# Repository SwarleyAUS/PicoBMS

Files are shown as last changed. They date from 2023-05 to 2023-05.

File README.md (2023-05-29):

# PicoBMS
Raspberry Pi Pico-based Battery Management System for 6-24S Lithium battery packs

Devleoped in KiCAD

Functionality:
- 6-24S cell monitoring and balancing through LTC6803-3
- XT30 charge and battery ports
- JST-XH balance jacks (12P & 13P)
- Dual thermister inputs
- Charge current sensing
- Opto-isolated CAN breakout from Pi Pico
- Back to back input MOSFETs for discharge protection

*** THIS DESIGN IS THEORETICALLY COMPLETE BUT UNTESTED ***



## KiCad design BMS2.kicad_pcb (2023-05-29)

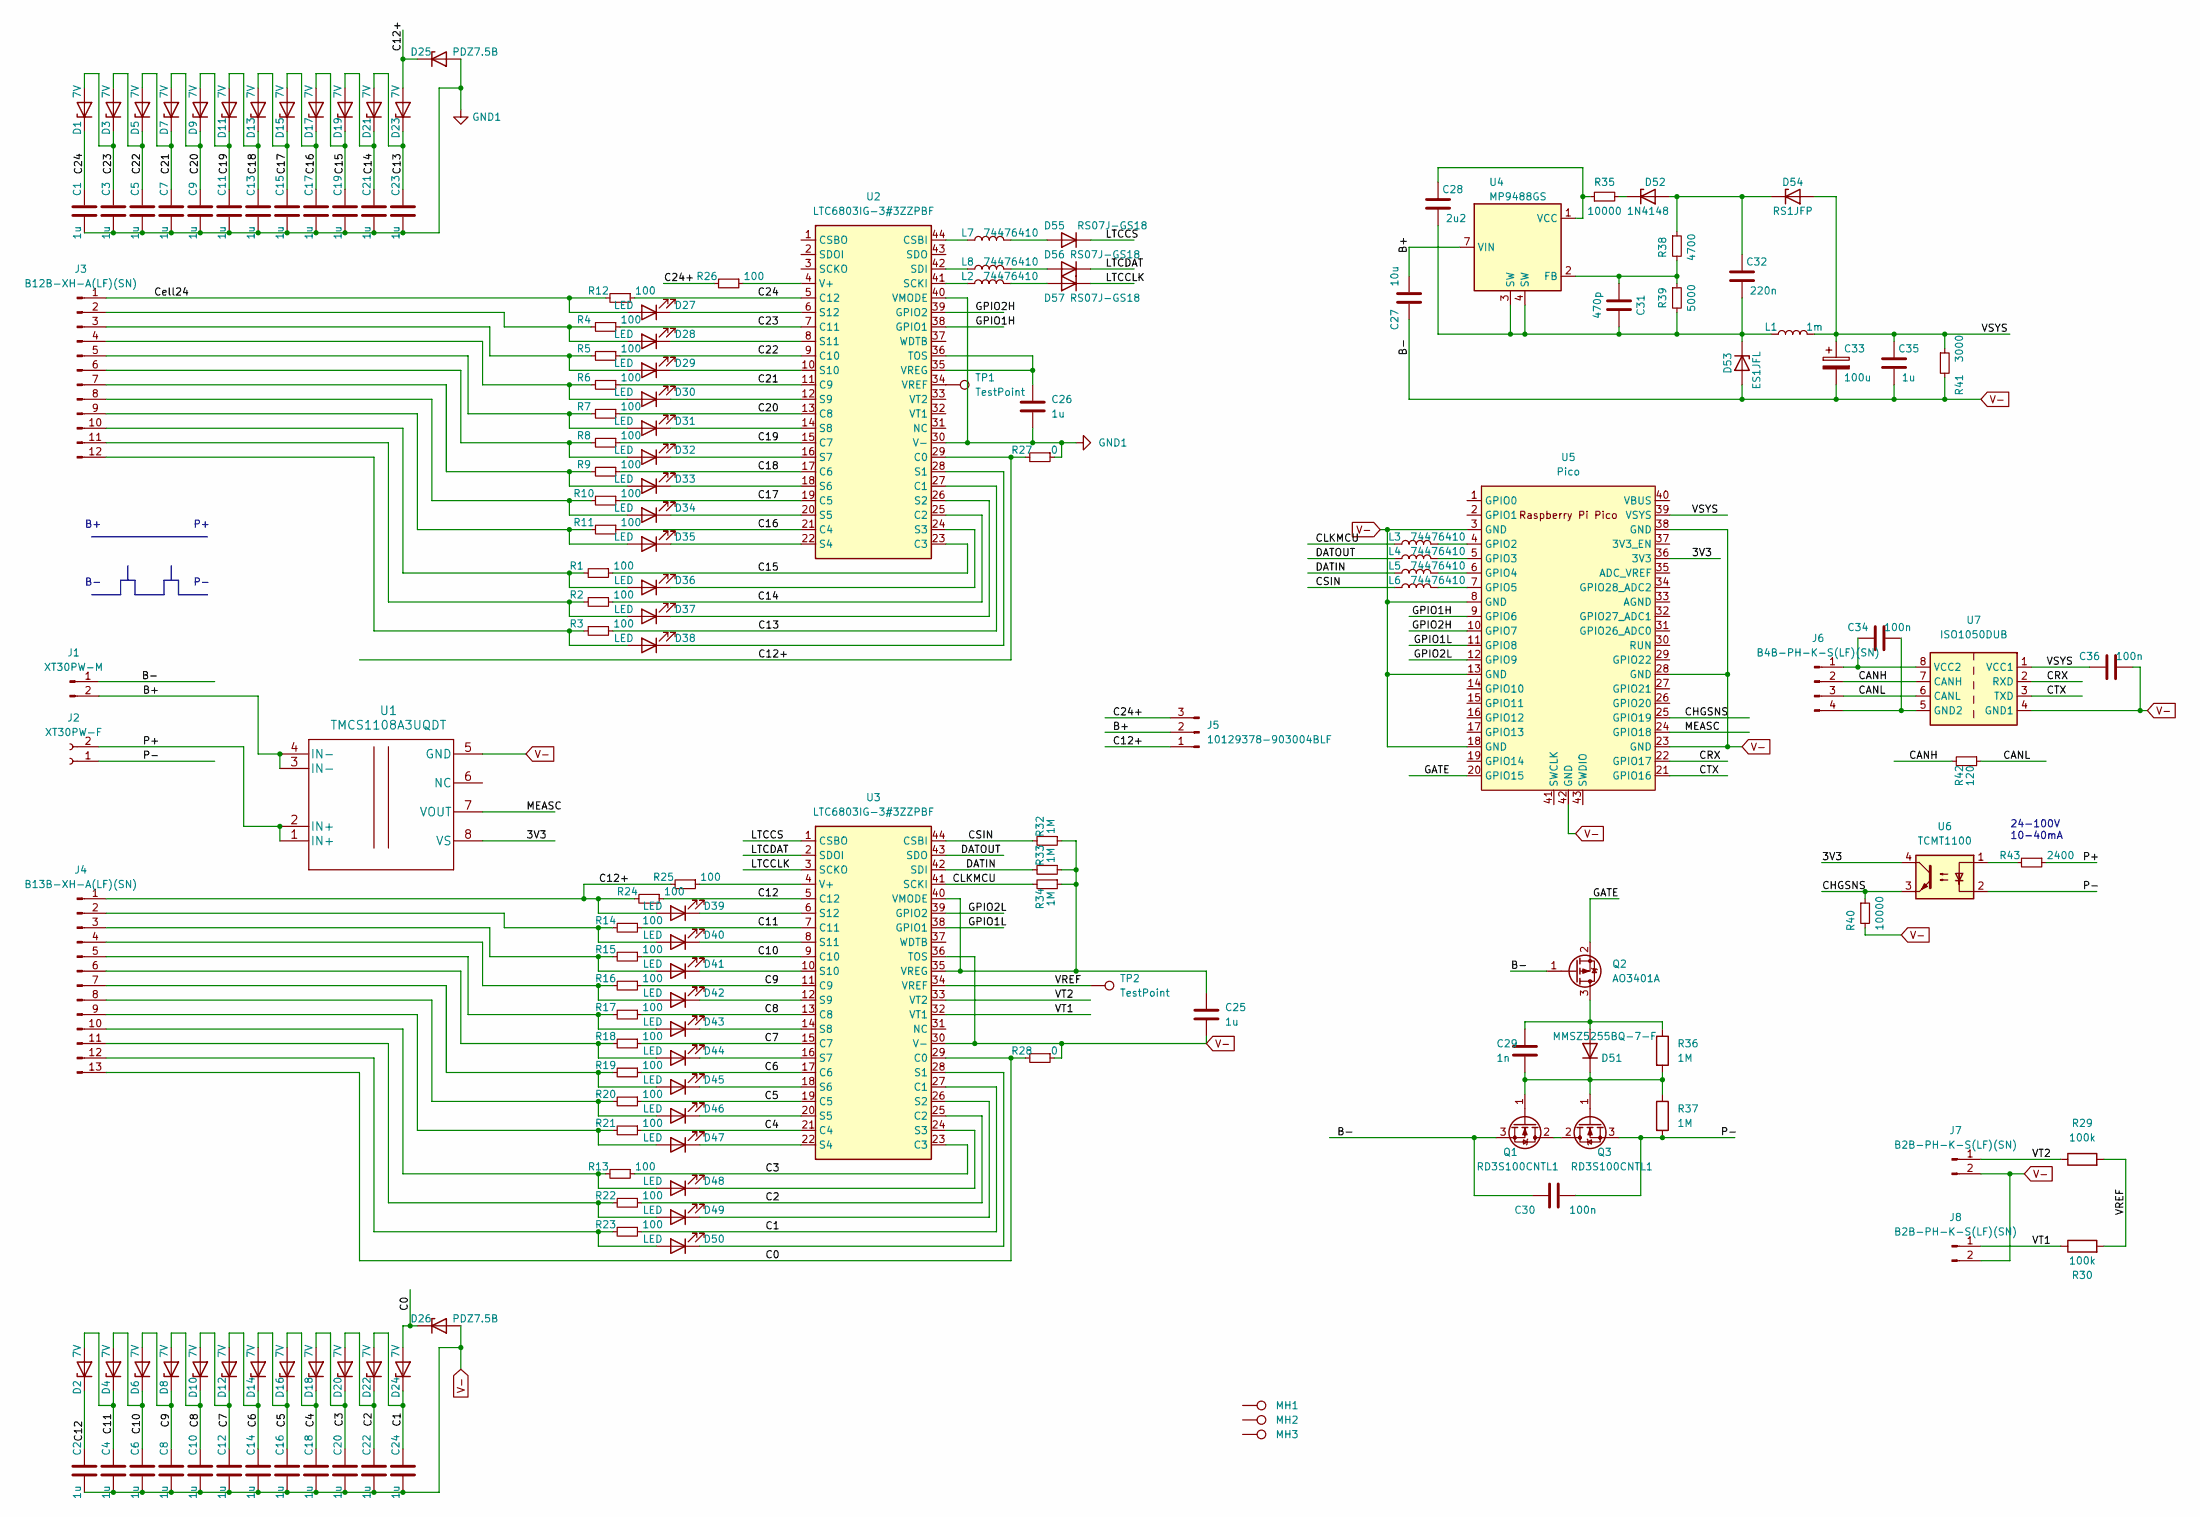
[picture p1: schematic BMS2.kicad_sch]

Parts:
C1, C2, C3, C4, C5, C6, C7, C8, C9, C10, C11, C12, C13, C14, C15, C16, C17, C18, C19, C20, C21, C22, C23, C24, C25, C26, C35: 1u; C_0603_1608Metric
C27: 10u; C_1210_3225Metric
C28: 2u2; C_0603_1608Metric
C29: 1n; C_0603_1608Metric
C30, C34, C36: 100n; C_0603_1608Metric
C31: 470p; C_0603_1608Metric
C32: 220n; C_0603_1608Metric
C33: 100u; CP_Elec_5x5.4
D1, D2, D3, D4, D5, D6, D7, D8, D9, D10, D11, D12, D13, D14, D15, D16, D17, D18, D19, D20, D21, D22, D23, D24: 7V; D_SOD-323
D25, D26: PDZ7.5B; D_SOD-323
D27, D28, D29, D30, D31, D32, D33, D34, D35, D36, D37, D38, D39, D40, D41, D42, D43, D44, D45, D46, D47, D48, D49, D50: LED; LED_0603_1608Metric
D51: MMSZ5255BQ-7-F; D_SOD-123
D52: 1N4148; D_SOD-323
D53: ES1JFL; D_SOD-123
D54: RS1JFP; D_SOD-123
D55, D56, D57: RS07J-GS18; D_SMF
J1: XT30PW-M; AMASS_XT30PW-M_1x02_P2.50mm_Horizontal
J2: XT30PW-F; AMASS_XT30PW-F_1x02_P2.50mm_Horizontal
J3: B12B-XH-A(LF)(SN); JST_XH_B12B-XH-A_1x12_P2.50mm_Vertical
J4: B13B-XH-A(LF)(SN); JST_XH_B13B-XH-A_1x13_P2.50mm_Vertical
J5: 10129378-903004BLF; PinHeader_1x03_P2.54mm_Vertical
J6: B4B-PH-K-S(LF)(SN); JST_PH_B4B-PH-K_1x04_P2.00mm_Vertical
J7, J8: B2B-PH-K-S(LF)(SN); JST_PH_B2B-PH-K_1x02_P2.00mm_Vertical
L1: 1m; L_1812_4532Metric
L2, L3, L4, L5, L6, L7, L8: 74476410; L_0805_2012Metric
MH1, MH2, MH3: TestPoint; MountingHole_3.2mm_M3
Q1, Q3: RD3S100CNTL1; TO-252-2
Q2: AO3401A; SOT-23
R1, R2, R3, R4, R5, R6, R7, R8, R9, R10, R11, R12, R13, R14, R15, R16, R17, R18, R19, R20, R21, R22, R23, R24, R25, R26: 100; R_0603_1608Metric
R27, R28: 0; R_0603_1608Metric
R29, R30: 100k; R_0603_1608Metric
R32, R33, R34, R36, R37: 1M; R_0603_1608Metric
R35, R40: 10000; R_0603_1608Metric
R38: 4700; R_0603_1608Metric
R39: 5000; R_0603_1608Metric
R41: 3000; R_0603_1608Metric
R42: 120; R_0603_1608Metric
R43: 2400; R_0603_1608Metric
TP1, TP2: TestPoint; TestPoint_THTPad_D1.5mm_Drill0.7mm
U1: TMCS1108A3UQDT; SOIC-8_3.9x4.9mm_P1.27mm
U2, U3: LTC6803IG-3#3ZZPBF; SSOP-44_5.3x12.8mm_P0.5mm
U4: MP9488GS; SOIC-8_3.9x4.9mm_P1.27mm
U5: Pico; RPi_Pico_SMD_TH
U6: TCMT1100; SOP-4_4.4x2.6mm_P1.27mm
U7: ISO1050DUB; SOP-8_6.62x9.15mm_P2.54mm

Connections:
/3V3: U1.8 (VS), U5.36 (3V3), U6.4
/B+: C27.2, J1.2, J5.2, U1.3 (IN-), U1.4 (IN-), U4.7 (VIN)
/C0: D24.2 (A), D26.1 (K), J4.13, R28.2, U3.29 (C0)
/C1: C24.1, D22.2 (A), D24.1 (K), R23.1, U3.27 (C1)
/C2: C22.1, D20.2 (A), D22.1 (K), R22.1, U3.25 (C2)
/C3: C20.1, D18.2 (A), D20.1 (K), R13.1, U3.23 (C3)
/C4: C18.1, D16.2 (A), D18.1 (K), R21.1, U3.21 (C4)
/C5: C16.1, D14.2 (A), D16.1 (K), R20.1, U3.19 (C5)
/C6: C14.1, D12.2 (A), D14.1 (K), R19.1, U3.17 (C6)
/C7: C12.1, D10.2 (A), D12.1 (K), R18.1, U3.15 (C7)
/C8: C10.1, D8.2 (A), D10.1 (K), R17.1, U3.13 (C8)
/C9: C8.1, D6.2 (A), D8.1 (K), R16.1, U3.11 (C9)
/C10: C6.1, D4.2 (A), D6.1 (K), R15.1, U3.9 (C10)
/C11: C4.1, D2.2 (A), D4.1 (K), R14.1, U3.7 (C11)
/C12: C2.1, D2.1 (K), R24.1, U3.5 (C12)
/C12+: D23.2 (A), D25.1 (K), D39.2 (A), J4.1, J5.1, R24.2, R25.2, R27.2, U2.29 (C0)
/C13: C23.1, D21.2 (A), D23.1 (K), R3.1, U2.27 (C1)
/C14: C21.1, D19.2 (A), D21.1 (K), R2.1, U2.25 (C2)
/C15: C19.1, D17.2 (A), D19.1 (K), R1.1, U2.23 (C3)
/C16: C17.1, D15.2 (A), D17.1 (K), R11.1, U2.21 (C4)
/C17: C15.1, D13.2 (A), D15.1 (K), R10.1, U2.19 (C5)
/C18: C13.1, D11.2 (A), D13.1 (K), R9.1, U2.17 (C6)
/C19: C11.1, D9.2 (A), D11.1 (K), R8.1, U2.15 (C7)
/C20: C9.1, D7.2 (A), D9.1 (K), R7.1, U2.13 (C8)
/C21: C7.1, D5.2 (A), D7.1 (K), R6.1, U2.11 (C9)
/C22: C5.1, D3.2 (A), D5.1 (K), R5.1, U2.9 (C10)
/C23: C3.1, D1.2 (A), D3.1 (K), R4.1, U2.7 (C11)
/C24: C1.1, D1.1 (K), R12.1, U2.5 (C12)
/C24+: J5.3, R26.2
/CANH: J6.2, R42.2, U7.7 (CANH)
/CANL: J6.3, R42.1, U7.6 (CANL)
/CHGSNS: R40.1, U5.25 (GPIO19), U6.3
/CLKMCU: L3.1, R34.2, U3.41 (SCKI)
/CRX: U5.22 (GPIO17), U7.2 (RXD)
/CSIN: L6.1, R32.2, U3.44 (CSBI)
/CTX: U5.21 (GPIO16), U7.3 (TXD)
/Cell24: D27.2 (A), J3.1, R12.2
/DATIN: L5.1, R33.2, U3.42 (SDI)
/DATOUT: L4.1, U3.43 (SDO)
/GATE: Q2.2 (S), U5.20 (GPIO15)
/GPIO1H: U2.38 (GPIO1), U5.9 (GPIO6)
/GPIO1L: U3.38 (GPIO1), U5.11 (GPIO8)
/GPIO2H: U2.39 (GPIO2), U5.10 (GPIO7)
/GPIO2L: U3.39 (GPIO2), U5.12 (GPIO9)
/LTCCLK: D57.1 (K), U3.3 (SCKO)
/LTCCS: D55.1 (K), U3.1 (CSBO)
/LTCDAT: D56.1 (K), U3.2 (SDOI)
/MEASC: U1.7 (VOUT), U5.24 (GPIO18)
/P+: J2.2, R43.1, U1.1 (IN+), U1.2 (IN+)
/P-: C30.2, J2.1, Q3.3 (S), R37.2, U6.2
/VREF: R29.2, R30.2, TP2.1, U3.34 (VREF)
/VSYS: C33.1, C35.1, C36.1, D54.2 (A), L1.2, R41.1, U5.39 (VSYS), U7.1 (VCC1)
/VT1: J8.1, R30.1, U3.32 (VT1)
/VT2: J7.1, R29.1, U3.33 (VT2)
GND1: C1.2, C3.2, C5.2, C7.2, C9.2, C11.2, C13.2, C15.2, C17.2, C19.2, C21.2, C23.2, C26.2, D25.2 (A), R27.1, U2.30 (V-), U2.40 (VMODE)
unnamed: C25.1, R32.1, R33.1, R34.1, U3.35 (VREG), U3.40 (VMODE)
unnamed: C26.1, U2.35 (VREG), U2.36 (TOS)
unnamed: C28.1, R35.1, U4.1 (VCC)
unnamed: C28.2, C31.1, C32.2, D53.1 (K), L1.1, R39.2, U4.3 (SW), U4.4 (SW)
unnamed: C29.1, D51.2 (K), Q1.1 (G), Q3.1 (G), R36.2, R37.1
unnamed: C29.2, D51.1 (A), Q2.3 (D), R36.1
unnamed: C31.2, R38.2, R39.1, U4.2 (FB)
unnamed: C32.1, D52.2 (A), D54.1 (K), R38.1
unnamed: C34.1, J6.1, U7.8 (VCC2)
unnamed: C34.2, J6.4, U7.5 (GND2)
unnamed: D27.1 (K), U2.6 (S12)
unnamed: D28.1 (K), U2.8 (S11)
unnamed: D28.2 (A), J3.2, R4.2
unnamed: D29.1 (K), U2.10 (S10)
unnamed: D29.2 (A), J3.3, R5.2
unnamed: D30.1 (K), U2.12 (S9)
unnamed: D30.2 (A), J3.4, R6.2
unnamed: D31.1 (K), U2.14 (S8)
unnamed: D31.2 (A), J3.5, R7.2
unnamed: D32.1 (K), U2.16 (S7)
unnamed: D32.2 (A), J3.6, R8.2
unnamed: D33.1 (K), U2.18 (S6)
unnamed: D33.2 (A), J3.7, R9.2
unnamed: D34.1 (K), U2.20 (S5)
unnamed: D34.2 (A), J3.8, R10.2
unnamed: D35.1 (K), U2.22 (S4)
unnamed: D35.2 (A), J3.9, R11.2
unnamed: D36.1 (K), U2.24 (S3)
unnamed: D36.2 (A), J3.10, R1.2
unnamed: D37.1 (K), U2.26 (S2)
unnamed: D37.2 (A), J3.11, R2.2
unnamed: D38.1 (K), U2.28 (S1)
unnamed: D38.2 (A), J3.12, R3.2
unnamed: D39.1 (K), U3.6 (S12)
unnamed: D40.1 (K), U3.8 (S11)
unnamed: D40.2 (A), J4.2, R14.2
unnamed: D41.1 (K), U3.10 (S10)
unnamed: D41.2 (A), J4.3, R15.2
unnamed: D42.1 (K), U3.12 (S9)
unnamed: D42.2 (A), J4.4, R16.2
unnamed: D43.1 (K), U3.14 (S8)
unnamed: D43.2 (A), J4.5, R17.2
unnamed: D44.1 (K), U3.16 (S7)
unnamed: D44.2 (A), J4.6, R18.2
unnamed: D45.1 (K), U3.18 (S6)
unnamed: D45.2 (A), J4.7, R19.2
unnamed: D46.1 (K), U3.20 (S5)
unnamed: D46.2 (A), J4.8, R20.2
unnamed: D47.1 (K), U3.22 (S4)
unnamed: D47.2 (A), J4.9, R21.2
unnamed: D48.1 (K), U3.24 (S3)
unnamed: D48.2 (A), J4.10, R13.2
unnamed: D49.1 (K), U3.26 (S2)
unnamed: D49.2 (A), J4.11, R22.2
unnamed: D50.1 (K), U3.28 (S1)
unnamed: D50.2 (A), J4.12, R23.2
unnamed: D52.1 (K), R35.2
unnamed: D55.2 (A), L7.2
unnamed: D56.2 (A), L8.2
unnamed: D57.2 (A), L2.2
unnamed: L2.1, U2.41 (SCKI)
unnamed: L3.2, U5.4 (GPIO2)
unnamed: L4.2, U5.5 (GPIO3)
unnamed: L5.2, U5.6 (GPIO4)
unnamed: L6.2, U5.7 (GPIO5)
unnamed: L7.1, U2.44 (CSBI)
unnamed: L8.1, U2.42 (SDI)
unnamed: Q1.2 (D), Q3.2 (D)
unnamed: R25.1, U3.4 (V+)
unnamed: R26.1, U2.4 (V+)
unnamed: R43.2, U6.1
unnamed: TP1.1, U2.34 (VREF)
V-: C2.2, C4.2, C6.2, C8.2, C10.2, C12.2, C14.2, C16.2, C18.2, C20.2, C22.2, C24.2, C25.2, C27.1, C30.1, C33.2, C35.2, C36.2, D26.2 (A), D53.2 (A), J1.1, J7.2, J8.2, Q1.3 (S), Q2.1 (G), R28.1, R40.2, R41.2, U1.5 (GND), U3.30 (V-), U3.36 (TOS), U5.3 (GND), U5.8 (GND), U5.13 (GND), U5.18 (GND), U5.23 (GND), U5.28 (GND), U5.38 (GND), U5.42 (GND), U7.4 (GND1)

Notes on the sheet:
24-100V 10-40mA

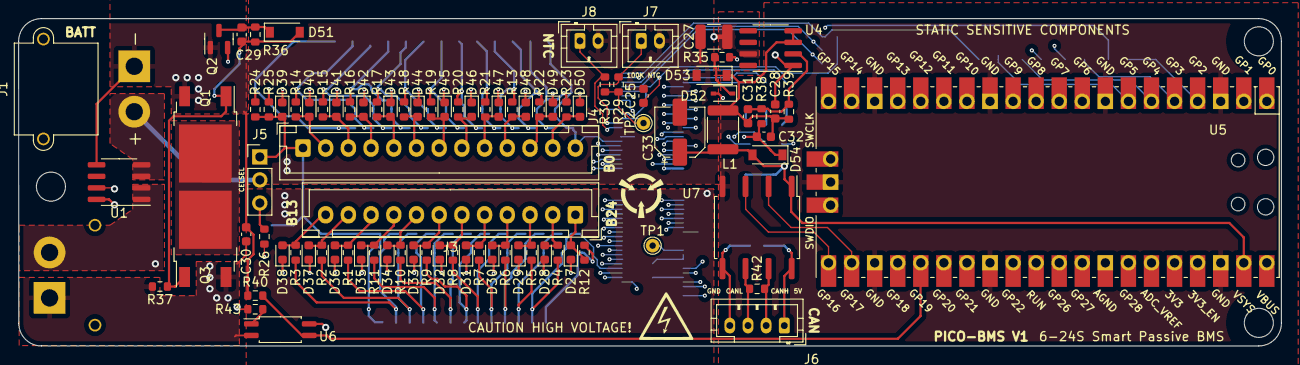
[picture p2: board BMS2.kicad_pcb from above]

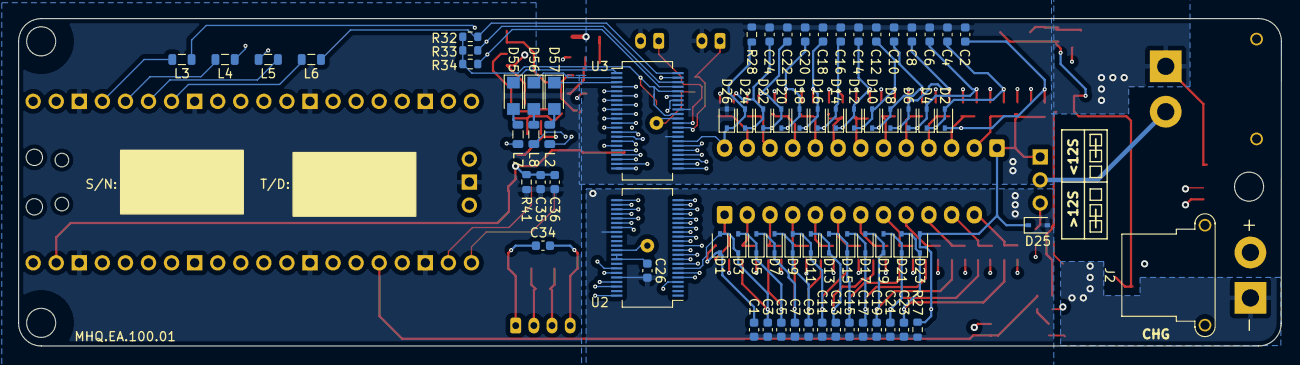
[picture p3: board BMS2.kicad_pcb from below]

Board: 4 copper layers, 139.0 x 36.0 mm, 166 parts (73 on the bottom side), 128 nets.
